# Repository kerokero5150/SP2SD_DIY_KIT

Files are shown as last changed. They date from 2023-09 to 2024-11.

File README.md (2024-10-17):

# SPIISD DIY KIT

<br>
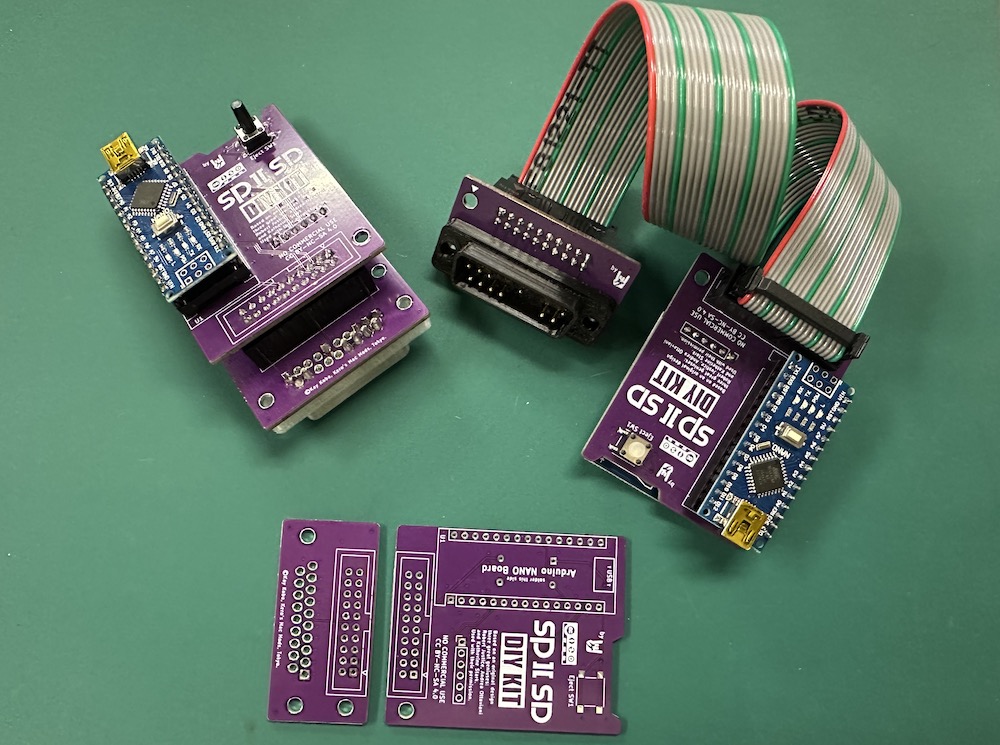
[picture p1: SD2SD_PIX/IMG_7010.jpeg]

# What is SPIISD ?
It is based on an open source project called SmartPortSD. 
Created by Australian genius [Robert Justice](https://web.archive.org/web/20230222233834/http://www.users.on.net/~rjustice/SmartportCFA/SmartportCFA.htm), SmartPortCFA was ported to Arduino hardware by Italian programmer genius [Andrea Ottaviani](https://github.com/aotta?fbclid=IwAR0_7cMKVhMVrHznB9bIub9ZmrmBlwAM3p6-_CQd0JFW1o736nUNZHyuTdw).  to porting to Arduino hardware. It was improved upon by [Katherine Stark](https://gitlab.com/nyankat/smartportsd) of Canada. She made available its ability to access four ProDOS-formatted 32MB PO files stored on a FAT32-formatted SD card. When she did this successfully, many wanted to build it.

*Got permission from the three geniuses I introduced earlier.<BR><BR>

We differentiated it with a name to distinguish it from other SmartportSD hardware (including unlicensed ones).<BR><BR>

<BR>
More details here (My Blog):
https://ameblo.jp/keroxiee1016/entry-12819341808.html

## Flashing Arduino Nano

Oct 15th, 2024: SmartportSD program has been updated to Ver.1.17, version 1.17 has been thoroughly tested with "SPIISD" hardware and has confirmed good performance. Fixed a problem with the Apple IIcPlus, and improved versatility with slower SD cards. Usage is the same as V.1.16.

May 8th, 2024: SmartportSD program has been updated to Ver.1.16 by Wing Yeung from [MFA2 work shop](http://www.mfa2lab.com). version 1.16 has been thoroughly tested with "SPIISD" hardware and has confirmed good performance. This same 1.16 program can work with both "SPIISD DIY KIT" and "SPIISD MINI". *We have not verified SmartportSD compatible devices from other manufacturers. I think they work well if they keep the same schematics.<BR>

- By placing "config.txt" at the root of the SD card, you can place various files without renaming them.<BR>
- Write 4x file names in "config.txt". SPIISD will only read files with that filename.
In addition to ".po", ".hdv" and ".2mg" can be used as extensions.<BR>
- Of course, you can put an unlimited number of images in the root of the SD card, but only the config.txt file will be read.<BR>
- If you do not place config.txt, you can also place four files from PART1.po as before.<BR>

You can flash your Arduino Nano via ArduinoIDE. Please download and use firmware of ["SmartportSD-1.17" folder](SmartportSD-1.17). If a new folder is created when using the Arduino IDE, please re-insert all the contents of this "SmartportSD-1.17" folder into the new folder. *The name of the ".ino" file should always be the same as the parent folder, so there is usually no problem if you use it as is.<BR>
<BR>
The Nano board you should choose is MEGA328P. Please do not buy MEGA168P as it has 38% insufficient capacity and cannot be flashed.<BR>
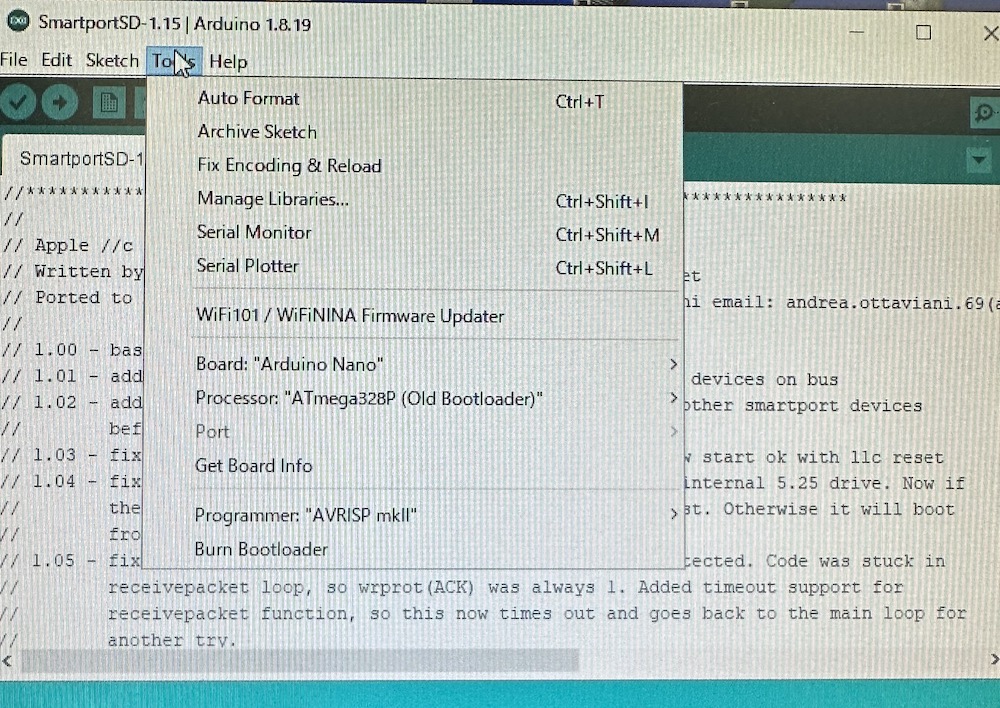
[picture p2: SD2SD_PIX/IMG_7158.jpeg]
<BR>
The Arduino IDE settings are as follows,<BR>
Board: "Arduino Nano"<BR>
Processor: "ATmega328P(Old Bootloader)"<BR>
Port: Number of USB port connected to Arduino Nano *In your PC<BR>
Programmer: "AVRISP mkII"<BR>

## Assemble
Uploaded on Sep 24, assembly instructions can be found [here](SP2SD_DIY_INST.pdf), You can see which parts should be attached where by looking at our [BOM](SP2SD_NANO_DIY_BOM.csv). 
<BR>
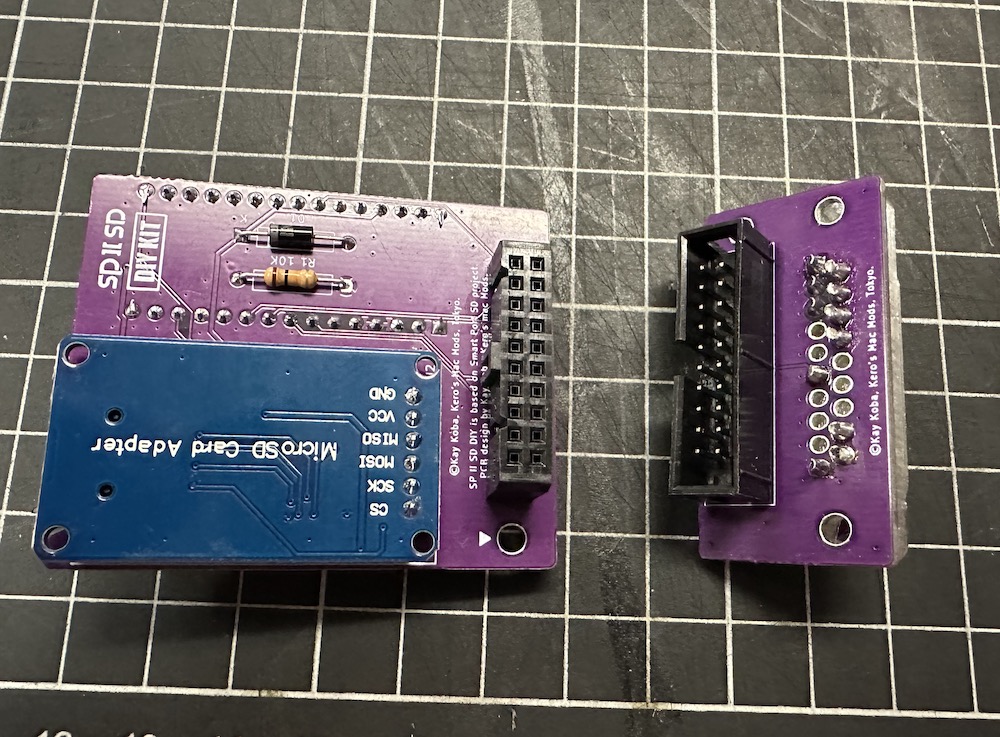
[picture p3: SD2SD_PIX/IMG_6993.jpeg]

<BR>
The IDC20 connector can be oriented in various ways depending on how you use it, When installing the male IDC20pin connector, be sure to make sure that the part is on the top side. When stacking two PCBs, make sure the hole and ▼ are in the same position. In that case, match the IDC20pin male and female connectors or connect them with a 2X10 pin header.<BR><BR>
日本語の組み立て説明書は[こちら](SP2SD_DIY_INST_JPN.pdf)から

## DB19 male connector

You can 3D print the base material and pull out the pins from a [DB25 male connector](https://www.amazon.com/PC-Accessories-Connectors-Connector-25-PACK/dp/B073KR622F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) and insert them, or purchase new pins from [AliExpress](https://www.aliexpress.com/item/1005002617586407.html?spm=a2g0o.order_list.order_list_main.16.55d11802jCHaOW). We have omitted unnecessary pins to make it simple for you to create. I will give out free .STL files that can be 3D printed. <BR><BR> DB19 connector file is [this](KEROS_DB19_V1.zip).

## 3D printed shell case

Our awesome friend [Mr Lurch](https://www.youtube.com/channel/UCMQ28v823w6p1ZnyiZDVwUg) completed the shell case design. This can be used by connecting boards A and B with pin headers without using cables.<BR><BR>
 [Here](https://www.thingiverse.com/thing:6235981) is the case stl files for integrated.<BR>
 [Here](https://www.thingiverse.com/thing:6248598) is the case stl files for cable connection.

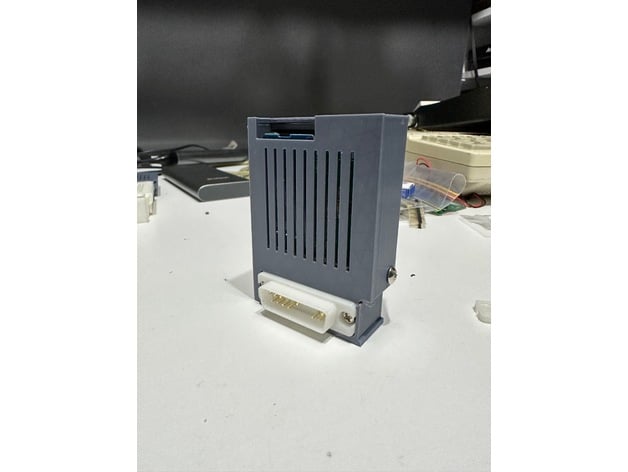
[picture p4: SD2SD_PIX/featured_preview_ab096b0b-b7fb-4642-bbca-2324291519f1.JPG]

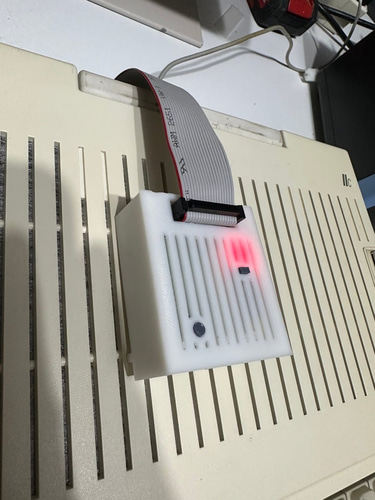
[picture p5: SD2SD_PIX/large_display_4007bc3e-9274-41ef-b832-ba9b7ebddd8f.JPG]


## Supported Apple II computers

<BR>
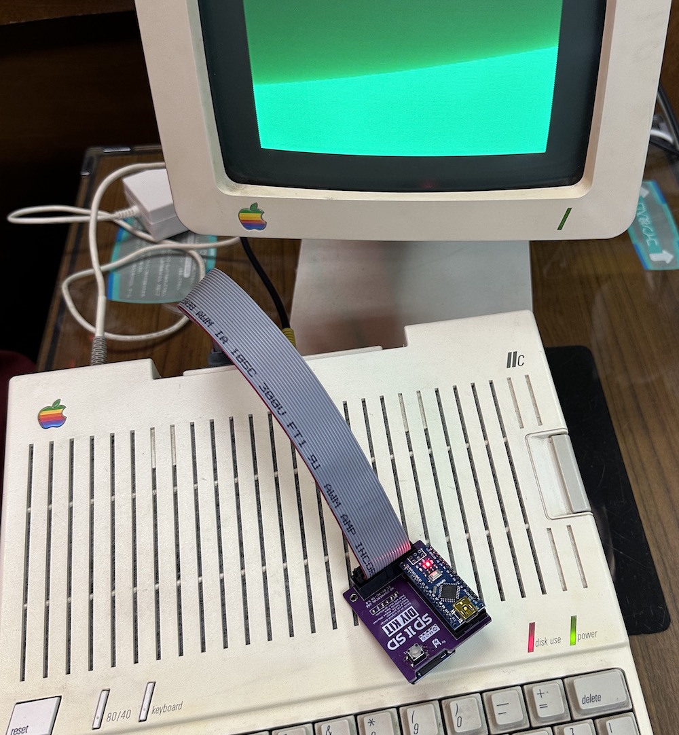
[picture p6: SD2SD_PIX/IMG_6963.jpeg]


<BR><BR>
- Apple IIgs　*Even you set the startup slot to #5 and remove other bootable devices the startup timing does not match, try the shortcut key "Open Apple" + "Control" + "Reset" to reboot. If you are new to IIgs, make sure to release key "Open Apple"　 last and it will reboot easily.<BR>
- Apple IIc, IIc Plus *In the case of IIc, Smartport cannot be used as is with older ROM 255, so a ROM upgrade is required. See the chapter bellow
- Apple IIe, IIe Enhanced, IIe Platinum, works well with Grappler Minus card (1) with SoftSP diy ROM V2, V3 and V6-a. It works into the #5 slot and use it via the DiskII card in the #6 slot. In other words, it is a card that connects SmartPort with two cards.<BR>*You can also use it via "Liron" card, BMOW also has a highly functional card called "Yellowstone", which can also be used. <BR>
- Apple II Plus, works well with GrapplerMinus card with SoftSP diy ROM V2, V3 and V6-a.<BR>

(1) We developed the [Grappler Minus card](https://github.com/kerokero5150/GrapplerMinus/blob/main/README.md), which overcomes timing issues. This is also open source and anyone can create it, but it is not allowed to be sold. It is also available for purchase at our store. <BR><BR>
If you use SoftSP with the Genuine "Grappler Plus" card, the functionality of SoftSP DIY will be limited due to the unnecessary circuitry of the printer interface. Specifically, it only works with Apple IIe, and only V2 and V3 ROMs can be used.

## Usage
<BR>
Use a FAT32(16) formatted MicroSD card. Most of the MicroSD cards currently on sale can be used as is.
Extension .po files can be used.<BR><BR>

### Usage V.1.17(1.16)
New firmware allows the use of three file extensions: ".po", ".hdv", ".2mg", each files with a maximum size of 32MB.
As we have upgraded to V.1.17(1.16), the new method for setting up the SD card is described below. From v1.16 onwards, if "config.txt" is not placed in the root, it will be automatically recognized and converted to the old method. Please refer to “2, Old method” when "config.txt" is not placed.＜BR>
Place "config.txt" in the root of the SD card, this is a standard text document, which can be created using any text editors. This is the table of contents for loading the specified file into the Apple II. The contents of "config.txt" must have a file name written on each line, and you can specify up to four files to launch. You can add as many files as you like up to the capacity of the SD card. However, SPIISD can only read the four files with the names written in config.txt. The file extensions are either ".po", ".hdv", or ".2mg". SPIISD will read from the first file written (on the first line). Please keep in mind that the file specification must always be 4 lines for 4files.

### Usage up to V.1.15<BR>
The Apple ProDOS disk image that can be used for SPIISD is a .PO file with a maximum size of 32MB. Place this file at the root of your micro SD card. Up to 4 files can be recognized. The first file name should be “PART1.PO”. As you can imagine, there can place four files, so from the second file on, name the files with regularity, such as "PART2.PO", "PART3.PO", and "PART4.PO".<BR>
For disk images with the .hdv extension, the catalog structure is the same, so you should be able to use them by simply renaming the file to .po. An APP called CiderPressV4 can convert other file extensions to .po.<BR><BR>
I think the most popular way to use SPIISD on the IIc is to use TotalReplay, a collection of old appleII games. <BR>
The IIgs supports GSOS. In this case, you can check all four files at the same time on the OS's finder. If you only have a IIgs, the SPIISD is the device with the best value for money.<BR><BR>
*If you change the extension from .hdv to .po and it doesn't work, you can use CiderPress to convert it to a .PO file. CiderPressV4 can be done on Windows 7 and up. *For Win98/ME/2K/XP there is an older version.<BR>
<BR>
CiderPress V4:<BR>(https://a2ciderpress.com)<BR><BR>
TotalReplay:<BR>(https://archive.org/details/TotalReplay)<BR><BR>

## To use Apple IIc's smart port
For Apple IIc, Smartport will not be enabled if ROM 255 is installed(Probably ROM0 as well). To check the ROM of your IIc, run the following program from the Basic prompt.
  PRINT PEEK (64447)
If the output number is "255", the ROM needs to be replaced. The ROM versions that Smartport can use are "3", "4" and ROM"4x". For these numbers, ROM replacement is not necessary.

The replaced ROMs are available [here](https://mirrors.apple2.org.za/Apple%20II%20Documentation%20Project/Computers/Apple%20II/Apple%20IIc/ROM%20Images/).
There is also the useful hacked [ROM4X](https://github.com/mgcaret/rom4x). This is a fairly new ROM updated in 2018.<BR><BR>

My recommendation is ROM4X.<BR>

If you want to swap the ROM from 255 to another ROM, you need to change the solder jumpers "W1" and "W2". 
255 is 16KB while other ROMs are 32KB. Enable 32KB by changing Pin27, which is A14, from pull-down to pull-up. 
See below for solder jumper locations. [External site](https://www.apple2faq.com/apple2faq/apple-iic-rom-upgrade/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)

## To get the SPIISD PCB

You can use [SPSD_DIY_NANO_GERBER.zip](SPSD_DIY_NANO_GERBER.zip)  and uploading it to JLCPCB or PCBWAY as it is.

<BR>
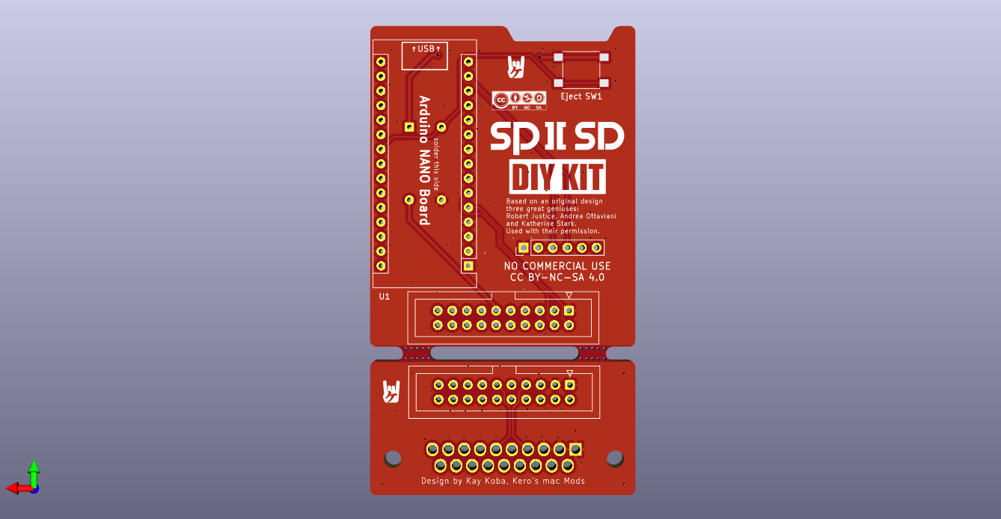
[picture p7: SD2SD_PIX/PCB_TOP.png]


The [SPIISD DIY kit](https://en.infinityproducts.co.jp/product-page/sp2sd-diykit-bare-pcb-board-a-b) comes complete with all parts, sold in our [store](https://en.infinityproducts.co.jp/shop-1). [SPIISD mini](https://en.infinityproducts.co.jp/product-page/spiisd-mini-for-iic-iicplus-iigs) is a compact hardware with fixed db19. It does not require assembly, so it is recommended for those who want to use it immediately, and for those who want a sense of unity with Apple IIc.

## Licenses

SmartportSD software licenses are listed [here](SMARTPORTSD_LICENSE.md) under the MIT license.
Ⓒ2023 Katherine Stark, Robert Justice, Andrea Ottaviani. All rights reserved.

This SPIISD hardware is licensed under a
[Creative Commons Attribution-ShareAlike 4.0 International License](https://creativecommons.org/licenses/by-nc-sa/4.0/).
Ⓒ 2023 Kay Koba, Kero's mac Mods, All rights reserved.


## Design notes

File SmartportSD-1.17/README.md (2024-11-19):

# SmartportSD FAT version 1.17

This is an enhancement of the [SmartportCFA/SmartportSD](http://www.users.on.net/~rjustice/SmartportCFA/SmartportCFA.htm) project by Robert Justice and Andrea Ottaviani. Instead of relying on four raw disk images written sequentially to an SD card, this version allows you to have up to four files on a FAT or FAT32 formatted SD card instead.

version 1.17: Improved version by Wing Yeung from [MFA2 work shop](http://www.mfa2lab.com). version 1.16 has been thoroughly tested with "SPIISD" hardware and has confirmed good performance.This same 1.16 program can work with both "SPIISD DIY KIT" and "SPIISD MINI". V1.17 adds support for IIcPlus. Memory allocation has been changed to dynamic allocation.

*We have not verified SmartportSD compatible devices from other manufacturers. I think they work well if they keep the same schematics.

# Usage

## Get the programs

Download it on [SPIISD](https://github.com/kerokero5150/SP2SD_DIY_KIT)'s Github. Copy and use the "SmartportSD-1.16" folder as is.

## Get the dependencies

Download the latest version of the [SdFat Arduino library](https://github.com/greiman/SdFat/) and install it in your Arduino libraries folder (that location is system-dependent so you'll have to figure out where it is for you, sorry).

## Compile and upload the code to the Arduino

## Wire up the Arduino

Follow the instructions on [Robert's page](http://www.users.on.net/~rjustice/SmartportCFA/SmartportSD.htm) for the wiring diagram.

### WARNING

Don't connect the Arduino USB and the +5V power to the Apple computer at the same time! Doing so could lead to a situation where +5V is backfeeding into the Apple from the Arduino, which is bad. 

If you plan on doing development work on this, or just want to watch the Arduino serial console for error messages, disconnect the +5V connection between the Apple II and the Arduino and power it only via the USB port. 

#### Technical details
The Apple needs more than the 500mA your modern computer's USB power supply can provide to boot up, plus it needs some other voltages as well. You could end up burning out your Arduino, your USB port, your Apple, or all of the above! (The most likely thing to happen is the USB port might shut off, or the Arduino will get hot and annoyed, though).

## Place images on the SD card

You can place unlimited images in the root or subfolders of the SD card. However, only the four files specified in config.txt can be mounted.
By placing "config.txt" at the root of the SD card, you can place various files without renaming them.
Write 4x file names in "config.txt". SPIISD will only read files with that filename.
In addition to ".po", ".hdv" and ".2mg" can be used as extensions.
If config.txt is not in the root, Name your images PART1.PO through PART4.PO. If you don't have four images that's OK, the missing ones will be skipped.

### NOTE

Images must be unadorned ProDOS-order images. They don't have to be ProDOS file systems though - ISO9660, DOS 3.3 and HFS should work (although they are currently untested).

## Change boot  order, if you want

The eject button, if you have it wired up, will work the same way as it does in Robert's version of the code. Hold the button down while power cycling the Apple (or pressing the Arduino reset button if the USB connection is supplying power) to choose the next of the four images as the new startup disk. Then power cycle (or reset) the Arduino again without the button held down to get ready for the next boot.

### WARNING

Make sure you have a pulldown resistor to ground on the eject button pin (Analog pin 3). If you don't, the Arduino will assume the button is always being held down and keep changing the boot device and never start its normal operation. Ask me how much debugging trouble this caused me!

## Boot the machine!

That's it, turn on the machine and it should boot from PART1.PO!

## BUGS

- The combination of this device, a ROM 03 IIgs, and a CFFA3000 card seems to  prevent booting from this device. If you have this setup, please test it and report back to me.
- The code for switching boot partitions is probably going to fail if files get renamed so that a previously present boot partition goes away.

Please report bugs or comment on the above via the GitLab issues page for the project.

April 27, 2024, Ver 1.16 edited by Kay Koba, Kero's Mac Mods 

(C) SmartportSD Project

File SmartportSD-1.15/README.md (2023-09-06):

# SmartportSD FAT version 1.15 - Mini version

NOTE: This version is designed to support the different pinout in the small version of the Smartport SD by Kero's Mac Mods. The pinout is different from the main project!

This is an enhancement of the [SmartportCFA/SmartportSD](http://www.users.on.net/~rjustice/SmartportCFA/SmartportCFA.htm) project by Robert Justice and Andrea Ottaviani. Instead of relying on four raw disk images written sequentially to an SD card, this version allows you to have up to four files on a FAT or FAT32 formatted SD card instead.

# Usage

## Get the code

Use git to clone the code and rename the enclosing folder to SmartportSD-1.15. (This is an annoying quirk of the Arduino environment, that requires the name of the code file to match the name of the folder it's in).

## Get the dependencies

Download the latest version of the [SdFat Arduino library](https://github.com/greiman/SdFat/) and install it in your Arduino libraries folder (that location is system-dependent so you'll have to figure out where it is for you, sorry).

## Compile and upload the code to the Arduino

## Wire up the Arduino

Follow the instructions on [Robert's page](http://www.users.on.net/~rjustice/SmartportCFA/SmartportSD.htm) for the wiring diagram.

### WARNING

Don't connect the Arduino USB and the +5V power to the Apple computer at the same time! Doing so could lead to a situation where +5V is backfeeding into the Apple from the Arduino, which is bad. 

If you plan on doing development work on this, or just want to watch the Arduino serial console for error messages, disconnect the +5V connection between the Apple II and the Arduino and power it only via the USB port. 

#### Technical details
The Apple needs more than the 500mA your modern computer's USB power supply can provide to boot up, plus it needs some other voltages as well. You could end up burning out your Arduino, your USB port, your Apple, or all of the above! (The most likely thing to happen is the USB port might shut off, or the Arduino will get hot and annoyed, though).

## Place images on the SD card

Name your images PART1.PO through PART4.PO. If you don't have four images that's OK, the missing ones will be skipped.

### NOTE

Images must be unadorned ProDOS-order images. They don't have to be ProDOS file systems though - ISO9660, DOS 3.3 and HFS should work (although they are currently untested).

## Change boot  order, if you want

The eject button, if you have it wired up, will work the same way as it does in Robert's version of the code. Hold the button down while power cycling the Apple (or pressing the Arduino reset button if the USB connection is supplying power) to choose the next of the four images as the new startup disk. Then power cycle (or reset) the Arduino again without the button held down to get ready for the next boot.

### WARNING

Make sure you have a pulldown resistor to ground on the eject button pin (Analog pin 3). If you don't, the Arduino will assume the button is always being held down and keep changing the boot device and never start its normal operation. Ask me how much debugging trouble this caused me!

## Boot the machine!

That's it, turn on the machine and it should boot from PART1.PO!

## BUGS

- The combination of this device, a ROM 03 IIgs, and a CFFA3000 card seems to  prevent booting from this device. If you have this setup, please test it and report back to me.
- The code for switching boot partitions is probably going to fail if files get renamed so that a previously present boot partition goes away.

Please report bugs or comment on the above via the GitLab issues page for the project.

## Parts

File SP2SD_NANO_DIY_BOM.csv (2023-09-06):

Comment | Designator | Footprint | Part #（optional）
Diode 1N5818 or 1N5817 | D1 | D_5W_P12.70mm_Horizontal | https://www.ebay.com/itm/201638741276
Resistor 1/4W 10K | R1 | R_Axial__Horizontal | https://www.ebay.com/itm/193643265885
DB19 MALE (DIY 3D printabe) | J3 | DSUB19 | https://mega.nz/file/3TpyBbZQ#Une7jokF2jOR1MvytVabhucY5tUW2j-zh7B3CO2GgGA
MicroSD Card Board | U2 | PinHeader_1x06_P2.54mm_Vertical | https://www.amazon.com/Maxmoral-Storage-Expansion-Interface-Adapter/dp/B07S3F4BLN
IDC 20 PIN MALE | J1, J2 | IDC20 BOX Header | https://www.ebay.com/itm/172306985804
Tactile Switch_6x6mm_SMD | SW1 | SW_Push_1P1T_NO_6x6mm_H9.5mm | https://www.ebay.com/itm/195947825136
Arduino Nano Board | U1 | Nano Board | https://www.amazon.com/ELEGOO-Arduino-ATmega328P-Without-Compatible/dp/B0713XK923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

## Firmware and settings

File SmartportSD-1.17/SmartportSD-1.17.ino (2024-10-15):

//*****************************************************************************
//
// Apple //c Smartport Compact Flash adapter
// Written by Robert Justice  email: rjustice(at)internode.on.net
// Ported to Arduino UNO with SD Card adapter by Andrea Ottaviani email: andrea.ottaviani.69(at)gmail.com
//
// 1.00 - basic read and write working for one partition
// 1.01 - add support for 4 partions, assume no other smartport devices on bus
// 1.02 - add correct handling of device ids, should work with other smartport devices
//        before this one in the drive chain.
// 1.03 - fixup smartort bus enable and reset handling, will now start ok with llc reset
// 1.04 - fixup rddata line handling so that it will work with internal 5.25 drive. Now if
//        there is a disk in the floppy drive, it will boot first. Otherwise it will boot
//        from the CF
// 1.05 - fix problem with internal disk being always write protected. Code was stuck in
//        receivepacket loop, so wrprot(ACK) was always 1. Added timeout support for
//        receivepacket function, so this now times out and goes back to the main loop for
//        another try.
// 1.1  - added support for being connected after unidisk 3.5. Need some more io pins to
//        support pass through, this is the next step.
//
// 1.12 - add eeprom storing of boot partition, cycling by eject button (PA3)
//
// 1.13 - Fixed an issue where the block number was calculated incorrectly, leading to
//        failed operations. Now Total Replay v3 works!
//
// 1.15 - Now uses FAT filesystem on the SD card instead of raw layout.
//
//
// 1.16 - Add support .hdv and .2mg (also .po), if add config.txt to the root of the sd card, 
//        it will read any file name. images added to subfolders will also be loaded.
//        if not specified in config.txt, usage is the same as in versions up to 1.15.
//        improvement by Wing Yueng.
//
// 1.17 - Add support IIcPlus. Fixed memory allocation to dynamic allocation.
//
//
// Apple disk interface is connected as follows:
// wrprot = pa5 (ack) (output)
// ph0    = pd2 (req) (input)
// ph1    = pd3       (input)
// ph2    = pd4       (input)
// ph3    = pd5       (input)
// rddata = pd6       (output from avr)
// wrdata = pd7       (input to avr)
//
//led i/o = pa4  (for led on when i/o on boxed version)
//eject button = pa3  (for boxed version, cycle between boot partitions)
//
//
// Serial port was connected for debug purposes. Most of the prints have been commented out.
// I left these in and these can be uncommented as required for debugging. Sometimes the
// prints add to much delay, so you need to be carefull when adding these in.
//
// NOTE: This is uses the ata code from the fat/fat32/ata drivers written by
//       Angelo Bannack and Giordano Bruno Wolaniuk and ported to mega32 by Murray Horn.
//
//*****************************************************************************

//x #include <SPI.h>
#include "SdFat.h"
#include <avr/eeprom.h>

// Set USE_SDIO to zero for SPI card access.
// Deprecated maintly because I don't want to
// maintain two codepaths
// #define USE_SDIO 0

#include <avr/io.h>
#include <string.h>
#include <stdio.h>
#include <avr/pgmspace.h>

#define PORT_REQ    PORTD   // Define the PORT to REQ
#define PIN_REQ     2     // Define the PIN number to REQ
#define PORT_ACK    PORTC   // Define the PORT to ACK
#define PIN_ACK     5     // Define the PIN number to ACK

#define NUM_PARTITIONS  4          // Number of 32MB Prodos partions supported


void print_hd_info(void);
void encode_data_packet (unsigned char source);   //encode smartport 512 byte data packet
int  decode_data_packet (void);                   //decode smartport 512 byte data packet
void encode_write_status_packet(unsigned char source, unsigned char status);
void encode_init_reply_packet (unsigned char source, unsigned char status);
void encode_status_reply_packet (struct device d);
int  packet_length (void);
int partition;
bool is_valid_image(File imageFile);

extern "C" unsigned char ReceivePacket(unsigned char*); //Receive smartport packet assembler function
extern "C" unsigned char SendPacket(unsigned char*);    //send smartport packet assembler function

//unsigned char packet_buffer[768];   //smartport packet buffer
//unsigned char packet_buffer[605];   //smartport packet buffer
unsigned char *packet_buffer;         //Wing
//unsigned char sector_buffer[512];   //ata sector data buffer
unsigned char status, packet_byte;
int count;
int initPartition;

// We need to remember several things about a device, not just its ID
struct device{
  File sdf;
  unsigned char device_id;              //to hold assigned device id's for the partitions
  unsigned long blocks;                 //how many 512-byte blocks this image has
  unsigned int header_offset;           //Some image files have headers, skip this many bytes to avoid them
  //bool online;                          //Whether this image is currently available
                                          //No longer used, user devices[...].sdf.isOpen() instead
  bool writeable;
};

device devices[NUM_PARTITIONS];

enum uiState{
  smartport,
  gotch,
  startup
};

uiState state=startup;


//The circuit:
//    SD card attached to SPI bus as follows:
// ** MOSI - pin 11 on Arduino Uno/Duemilanove/Diecimila
// ** MISO - pin 12 on Arduino Uno/Duemilanove/Diecimila
// ** CLK - pin 13 on Arduino Uno/Duemilanove/Diecimila
// ** CS - depends on your SD card shield or module.
//     Pin 10 used here

// Change the value of chipSelect if your hardware does
// not use the default value, SS.  Common values are:
// Arduino Ethernet shield: pin 4
// Sparkfun SD shield: pin 8
// Adafruit SD shields and modules: pin 10

const uint8_t chipSelect = 10;
const uint8_t ejectPin = 17;
const uint8_t statusledPin = 18;

// Don't actually use this, deprecated for simplicity
// Set USE_SDIO to zero for SPI card access.
//
// Initialize at highest supported speed not over 50 MHz.
// Reduce max speed if errors occur.

/*
   Set DISABLE_CHIP_SELECT to disable a second SPI device.
   For example, with the Ethernet shield, set DISABLE_CHIP_SELECT
   to 10 to disable the Ethernet controller.
*/
const int8_t DISABLE_CHIP_SELECT = 0;  // -1
//
// Pin numbers in templates must be constants.


/* Deprecated because I don't want to maintain two code paths
#if USE_SDIO
// Use faster SdioCardEX
SdioCardEX sd;
// SdioCard card;
#else  // USE_SDIO
Sd2Card sd;
#endif  // USE_SDIO
*/


SdFat sdcard;
// Name the SD object different from the above "sd"
// so that if we acciedntally use "sd" anywhere the
// compiler will catch it
//SdBaseFile sdf;
//todo: dynamic(?) array of files selected by user
//File partition1;

//File sdf[4];

//------------------------------------------------------------------------------

void setup() {
  //sdf[0] = &sdf1;
  //sdf[1] = &sdf2;
  // put your setup code here, to run once:
  mcuInit();
  Serial.begin(230400);
  Serial.print(F("\r\nSmartportSD v1.17a\r\n"));
  initPartition = eeprom_read_byte(0);
  if (initPartition == 0xFF) initPartition = 0;
  initPartition = (initPartition % 4);
  Serial.print(F("\r\nBoot partition: "));
  Serial.print(initPartition, DEC);

  pinMode(ejectPin, INPUT);
  print_hd_info(); //bad! something that prints things shouldn't do essential setup

  Serial.print(F("\r\nFree memory before opening images: "));
  Serial.print(freeMemory());

  String part = "PART";
////////<Wing
  SdFile myFile("config.txt", O_READ);
  // check for open error
  if (myFile.isOpen()) {
    unsigned char n;
    packet_buffer = (unsigned char *)malloc(100);    
    for(unsigned char i=0; i<NUM_PARTITIONS; i++){
      n = myFile.fgets(packet_buffer, 100);
      if(n>0) {
        if (packet_buffer[n - 1] == '\n') {
          packet_buffer[n-1] = 0;//Serial.print(n, DEC);
        }
        Serial.print("\r\n");           
        Serial.print((char*)packet_buffer);      
      }
      open_image(devices[i],(char*)packet_buffer);
      if(!devices[i].sdf.isOpen()){
        Serial.print(F("\r\nImage "));
        Serial.print(F(" open error!"));
      }
      else {
        if ((packet_buffer[n-4]=='2')&&((packet_buffer[n-3]&0xdf)=='M')&&((packet_buffer[n-2]&0xdf)=='G')) devices[i].header_offset=64;
        else devices[i].header_offset=0;
      }
      Serial.print(F("\r\nFree memory after opening image "));
      Serial.print(F(": "));
      Serial.print(freeMemory(), DEC);
      if (!myFile.available()) break;
    }
    free(packet_buffer);
    myFile.close();    
  }
  else  
////////Wing>
  for(unsigned char i=0; i<NUM_PARTITIONS; i++){
    //TODO: get file names from EEPROM
    open_image(devices[i], (part+(i+1)+".po") );
    if(!devices[i].sdf.isOpen()){
      Serial.print(F("\r\nImage "));
      Serial.print(i, DEC);
      Serial.print(F(" open error!"));
    }
    Serial.print(F("\r\nFree memory after opening image "));
    Serial.print(i);
    Serial.print(F(": "));
    Serial.print(freeMemory(), DEC);
  }  
    packet_buffer = (unsigned char *)malloc(605);
}

//*****************************************************************************
// Function: main loop
// Parameters: none
// Returns: 0
//
// Description: Main function for Apple //c Smartport Compact Flash adpater
//*****************************************************************************


void loop() {

  // put your main code here, to run repeatedly:

  unsigned long int block_num;
  unsigned char LBH, LBL, LBN, LBT, LBX;

  int number_partitions_initialised = 1;
  int noid = 0;
  int count;
  int ui_command;
  bool sdstato;
  unsigned char source, status, phases, status_code;
  //Serial.print(F("\r\nloop"));

  DDRD = 0x00;

  PORTD &= ~(_BV(6));    // set RD low
  interrupts();
  while (1) {
    state = smartport;

    if (digitalRead(ejectPin) == HIGH) rotate_boot();
    

    noid = 0;  //reset noid flag
    DDRC = 0xDF; //set ack (wrprot) to input to avoid clashing with other devices when sp bus is not enabled

    // read phase lines to check for smartport reset or enable
    phases = (PIND & 0x3c) >> 2;

    //Serial.print(phases);
    switch (phases) {

      // phase lines for smartport bus reset
      // ph3=0 ph2=1 ph1=0 ph0=1

      case 0x05:
        Serial.print(F("\r\nReset\r\n"));

        //Serial.print(number_partitions_initialised);
        // monitor phase lines for reset to clear
        while ((PIND & 0x3c) >> 2 == 0x05);
        number_partitions_initialised = 1; //reset number of partitions init'd
        noid = 0;   // to check if needed
        for (partition = 0; partition < NUM_PARTITIONS; partition++) //clear device_id table
          devices[partition].device_id = 0;
        break;

      // phase lines for smartport bus enable
      // ph3=1 ph2=x ph1=1 ph0=x
      case 0x0a:
      case 0x0b:
      case 0x0e:
      case 0x0f:
        //Serial.print(("E ")); //this is timing sensitive, so can't print to much here as it takes to long
        noInterrupts();
        DDRC = 0xFF;   //set ack to output, sp bus is enabled
        if ((status = ReceivePacket( (unsigned char*) packet_buffer))) {
          interrupts();
          break;     //error timeout, break and loop again
        }
        interrupts();

        //Serial.print(F("\r\nHere's our packet!"));
        //print_packet ((unsigned char*) packet_buffer, packet_length());

        // lets check if the pkt is for us
        if (packet_buffer[14] != 0x85)  // if its an init pkt, then assume its for us and continue on
        {
          //Serial.print(F("\r\nNot 0x85!"));
          
          // else check if its our one of our id's
          for  (partition = 0; partition < NUM_PARTITIONS; partition++)
          {
            if ( devices[(partition + initPartition) % NUM_PARTITIONS].device_id != packet_buffer[6])  //destination id
              noid++;
          }
          if (noid == NUM_PARTITIONS)  //not one of our id's
          {
            delay(100);
            Serial.print(F("\r\nNot our ID!"));
            //printf_P(PSTR("\r\nnot ours\r\n") );
            DDRC = 0xDF; //set ack to input, so lets not interfere
            PORTC &= ~(_BV(5));   //set ack low, for next time its an output
            while (PINC & 0x20);  //wait till low other dev has finished receiving it
            //printf_P(PSTR("a ") );
            //print_packet ((unsigned char*) packet_buffer, packet_length());


            //assume its a cmd packet, cmd code is in byte 14
            //now we need to work out what type of packet and stay out of the way
            switch (packet_buffer[14]) {
              case 0x80:  //is a status cmd
              case 0x83:  //is a format cmd
              case 0x81:  //is a readblock cmd
                while (!(PINC & 0x20));   //wait till high
                //Serial.print(F("A ")) );
                while (PINC & 0x20);      //wait till low
                //Serial.print(F(("a ")) );
                while (!(PINC & 0x20));  //wait till high
                //Serial.print(F(("A\r\n")) );
                break;
              case 0x82:  //is a writeblock cmd
                while (!(PINC & 0x20));   //wait till high
                //Serial.print(F(("W ")) );
                while (PINC & 0x20);      //wait till low
                //Serial.print(F(("w ")) );
                while (!(PINC & 0x20));   //wait till high
                //Serial.print(F("W\r\n")) );
                while (PINC & 0x20);      //wait till low
                //Serial.print(F(("w ")) );
                while (!(PINC & 0x20));   //wait till high
                //Serial.print(F("W\r\n") );
                break;
            }
            break;  //not one of ours
          }
        }

        //else it is ours, we need to handshake the packet
        //Serial.print(F("\r\nBW"));
        PORTC &= ~(_BV(5));   //set ack low
        while (PIND & 0x04);   //wait for req to go low
        //Serial.println(F("\r\nAW"));
        //Not safe to assume it's a normal command packet, GSOS may throw
        //us several extended packets here and then crash 
        //Refuse an extended packet
        source = packet_buffer[6];
        //Check if its one of ours and an extended packet
        //Serial.println(packet_buffer[8], HEX);
        //Serial.println(packet_buffer[14], HEX);
        /*
        if(is_ours(source) && packet_buffer[8] >= 0xC0 && packet_buffer[14] >= 0xC0) { 
          Serial.print(F("\r\nRefusing extended packet! "));
          Serial.print(source, HEX);
          
          delay(50);
          encode_error_reply_packet(source);
          noInterrupts();
          DDRD = 0x40; //set rd as output
          status = SendPacket( (unsigned char*) packet_buffer);
          DDRD = 0x00; //set rd back to input so back to tristate
          interrupts();
          Serial.print(F("\r\nRefused packet!"));
          delay(100);
          break;
        }*/
        
          
        //assume its a cmd packet, cmd code is in byte 14
        //Serial.print(F("\r\nCMD:"));
        //Serial.print(packet_buffer[14],HEX);
        //print_packet ((unsigned char*) packet_buffer,packet_length());
        if(packet_buffer[14]>=0xC0){
           // Serial.print(F("\r\nExtended packet!"));
           // Serial.print(F("\r\nHere's our packet!"));
           // print_packet ((unsigned char*) packet_buffer, packet_length());
           // delay(50);
        }

        switch (packet_buffer[14]) {

          case 0x80:  //is a status cmd
            digitalWrite(statusledPin, HIGH);
            source = packet_buffer[6];
            for (partition = 0; partition < NUM_PARTITIONS; partition++) { //Check if its one of ours
              if (devices[(partition + initPartition) % NUM_PARTITIONS].device_id == source
                && devices[(partition + initPartition) % NUM_PARTITIONS].sdf.isOpen() ) {  //yes it is, and it's online, then reply
                //Added (unsigned short) cast to ensure calculated block is not underflowing.
                status_code = (packet_buffer[19] & 0x7f); // | (((unsigned short)packet_buffer[16] << 3) & 0x80);
                //Serial.print(F("\r\nStatus code: "));
                //Serial.print(status_code);
                //print_packet ((unsigned char*) packet_buffer, packet_length());
                //Serial.print(F("\r\nHere's the decoded status packet because frig doing it by hand!"));
                //decode_data_packet();
                //print_packet((unsigned char*) packet_buffer, 9); //Standard SmartPort command is 9 bytes
                //if (status_code |= 0x00) { // TEST
                //  Serial.print(F("\r\nStatus not zero!! ********"));
                //  print_packet ((unsigned char*) packet_buffer,packet_length());}
                if (status_code == 0x03) { // if statcode=3, then status with device info block
                  Serial.print(F("\r\n******** Sending DIB! ********"));
                  encode_status_dib_reply_packet(devices[(partition + initPartition) % NUM_PARTITIONS]);
                  //print_packet ((unsigned char*) packet_buffer,packet_length());
                  delay(50);
                } else {  // else just return device status
                  /*
                  Serial.print(F("\r\n-------- Sending status! --------"));
                  Serial.print(F("\r\nSource: "));
                  Serial.print(source,HEX);
                  Serial.print(F(" Partition ID: "));
                  Serial.print(devices[(partition + initPartition) % NUM_PARTITIONS].device_id, HEX);
                  Serial.print(F(" Status code: "));
                  Serial.print(status_code, HEX);
                  */
                  encode_status_reply_packet(devices[(partition + initPartition) % NUM_PARTITIONS]);        
                }
                noInterrupts();
                DDRD = 0x40; //set rd as output
                status = SendPacket( (unsigned char*) packet_buffer);
                DDRD = 0x00; //set rd back to input so back to tristate
                interrupts();
                //printf_P(PSTR("\r\nSent Packet Data\r\n") );
                //print_packet ((unsigned char*) packet_buffer,packet_length());
                digitalWrite(statusledPin, LOW);
              }
            }
            break;


          /*case 0xC1:
            Serial.print(F("\r\nExtended read! Not implemented!"));
            break;*/
          case 0xC2:
            Serial.print(F("\r\nExtended write! Not implemented!"));
            break;
          case 0xC3:
            Serial.print(F("\r\nExtended format! Not implemented!"));
            break;
          case 0xC5:
            Serial.print(F("\r\nExtended init! Not implemented!"));
            break;

          case 0xC0:  //Extended status cmd
            digitalWrite(statusledPin, HIGH);
            source = packet_buffer[6];
            //Serial.println(source, HEX);
            for (partition = 0; partition < NUM_PARTITIONS; partition++) { //Check if its one of ours
              if (devices[(partition + initPartition) % NUM_PARTITIONS].device_id == source) {  //yes it is, then reply
                //Added (unsigned short) cast to ensure calculated block is not underflowing.
                status_code = (packet_buffer[21] & 0x7f);
                 Serial.print(F("\r\nExtended Status CMD:"));
                 Serial.print(status_code, HEX);
                 print_packet ((unsigned char*) packet_buffer,packet_length());
                 if (status_code == 0x03) { // if statcode=3, then status with device info block
                  Serial.println(F("Extended status DIB!"));
                } else {  // else just return device status
                  //Serial.print(F("\r\nExtended status non-DIB! Part: "));
                  //Serial.print(partition, HEX);
                  //Serial.print(F(" code: "));
                  //Serial.print(status_code, HEX);
                  //delay(50);
                  encode_extended_status_reply_packet(devices[(partition + initPartition) % NUM_PARTITIONS]);        
                }
                noInterrupts();
                DDRD = 0x40; //set rd as output
                status = SendPacket( (unsigned char*) packet_buffer);
                DDRD = 0x00; //set rd back to input so back to tristate
                interrupts();
                //printf_P(PSTR("\r\nSent Packet Data\r\n") );
                //print_packet ((unsigned char*) packet_buffer,packet_length());
                //Serial.print(F("\r\nStatus CMD"));
                digitalWrite(statusledPin, LOW);
              }
            }
            //Serial.print(F("\r\nHere's our reply!"));
            //print_packet ((unsigned char*) packet_buffer, packet_length());
            //*/
            break;
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

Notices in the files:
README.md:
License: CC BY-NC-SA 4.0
